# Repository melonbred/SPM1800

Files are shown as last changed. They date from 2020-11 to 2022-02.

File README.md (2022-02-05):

# SPM1800
This is a PCB for a southpaw mini 1800 layout keyboard with the following features:

- Big bar and split bar support
- MX or Alps style switches
- Two independent rotary encoders
- USB Type-C
- Breakout pins for RGB underglow
- Breakout pin for USB shield ground

## WARNING
This PCB has been tested for functionality. However, please review the project files prior to placing an order for manufacturing. Users should be warned that they are manufacturing this at their own risk. 

## Layout
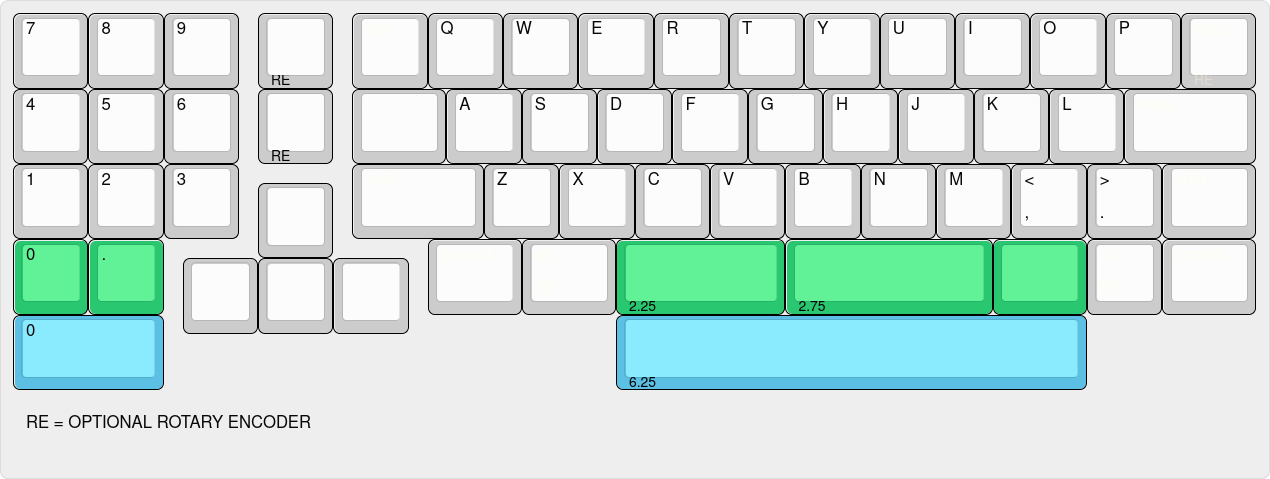
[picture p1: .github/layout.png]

[KLE](http://www.keyboard-layout-editor.com/#/gists/ef914cc294dadcf20cfa8c7b7239d802)

## PCB

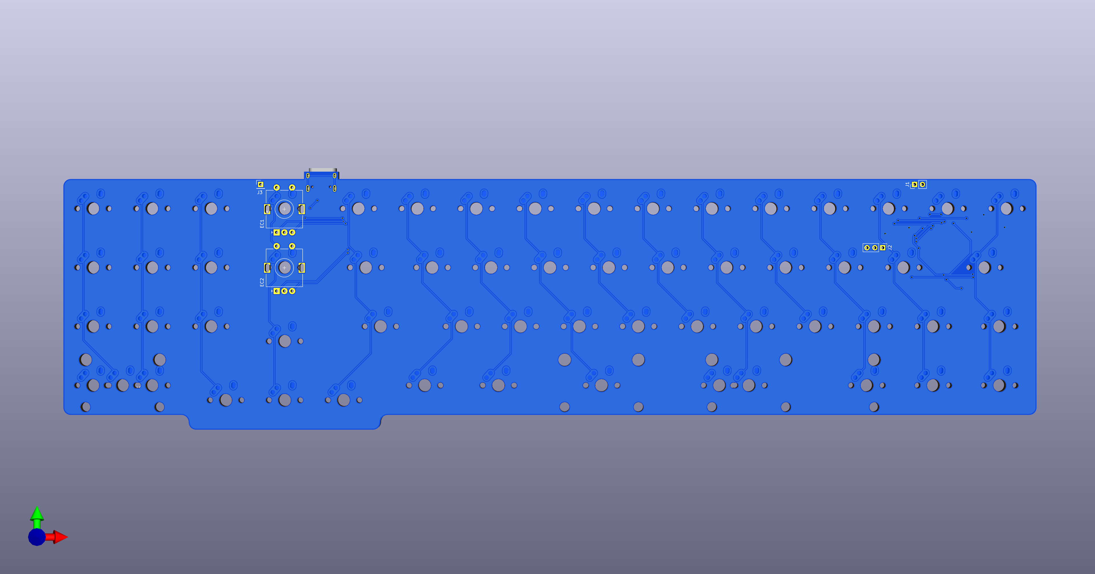
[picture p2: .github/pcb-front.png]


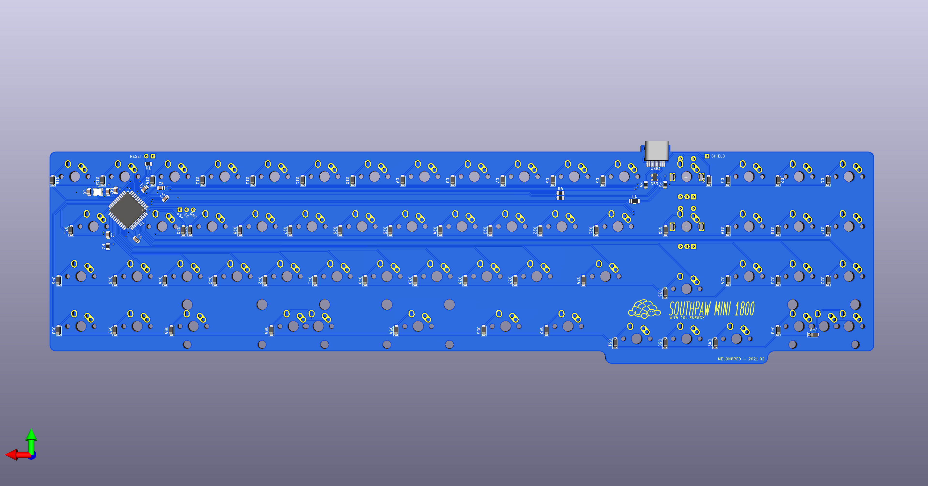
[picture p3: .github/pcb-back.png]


## BOM

| Designator | Description | Package | QTY | LCSC Part Number |
|---|---|---|-----|---|
|C1, C2, C3, C4|Capacitor - 0.1uF|0805|4|C28233|
|C5|Capacitor - 10uF|0805|1|C15850|
|C6, C7|Capacitor - 22pF|0805|2|C1804|
|C8|Capacitor - 1uF|0805|1|C28323|
|D1 - D58|Diode - 1N4148|SOD-123|58|C466653|
|D59|ESD Protection Diode - PRTR5V0U2X|SOD-143B|1|C12333|
|F1|Fuse 24V - 500mA|1206|1|C70076|
|R1, R2|Resistor - 10k|0805|2|C17414|
|R3, R4|Resistor - 5.1k|0805|2|C27834|
|R5, R6|Resistor - 22|0805|2|C17561|
|U1|Atmega32u4|QFP-44_10x10mm_P0.8mm|1|C44854|
|USB1|HRO-TYPE-C-31-M-12|HRO-TYPE-C-31-M-12|1|C165948|
|Y1|Crystal 16Mhz 3.2x2.5mm, 4 pad|3225|1|C156247|

## QMK Firmware
Firmware has been written but not tested at this time. QMK files can be found [here](https://github.com/melonbred/SPM1800/tree/master/QMK).

## Additional Notes
This project uses KiCAD libraries maintained by ai03:

- [MX_Alps_Hybrid](https://github.com/ai03-2725/MX_Alps_Hybrid)
- [random-keyboard-parts.pretty](https://github.com/ai03-2725/random-keyboard-parts.pretty)
- [Type-C.pretty](https://github.com/ai03-2725/Type-C.pretty)

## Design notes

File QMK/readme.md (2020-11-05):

# spm1800

spm1800

A short description of the keyboard/project

* Keyboard Maintainer: [melonbred](https://github.com/yourusername)
* Hardware Supported: The PCBs, controllers supported
* Hardware Availability: Links to where you can find this hardware

Make example for this keyboard (after setting up your build environment):

    make spm1800:default

See the [build environment setup](https://docs.qmk.fm/#/getting_started_build_tools) and the [make instructions](https://docs.qmk.fm/#/getting_started_make_guide) for more information. Brand new to QMK? Start with our [Complete Newbs Guide](https://docs.qmk.fm/#/newbs).

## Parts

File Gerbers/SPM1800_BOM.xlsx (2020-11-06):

Designator | Quantity | Value | Footprint | LCSC Part #
C2, C3, C4, C1 | 4 | 0.1uF | Capacitor_SMD:C_0805_2012Metric | C730459
C5 | 1 | 10uF | Capacitor_SMD:C_0805_2012Metric | C307520
C6, C7 | 2 | 22pF | Capacitor_SMD:C_0805_2012Metric | C1804
C8 | 1 | 1uF | Capacitor_SMD:C_0805_2012Metric | C116352
D1, D2, D3, D17, D18, D19, D32, D33, D34, D47, D48, D4, D20, D35, D49, D50, D5, D6, D7, D8, D9, D10, D11, D12, D13, D14, D15, D16, D21, D22, D23, D24, D25, D26, D27, D28, D29, D30, D31, D36, D37, D38, D39, D40, D41, D42, D43, D44, D45, D46, D51, D52, D53, D54, D55, D56, D57, D58 | 58 | 1N4148 | Diode_SMD:D_SOD-123 | C466653
D59 | 1 | PRTR5V0U2X | SOT143B | C78442
F1 | 1 | Polyfuse_Small | Fuse:Fuse_1206_3216Metric | C70076
R1 R2 | 2 | 10k | Resistor_SMD:R_0805_2012Metric | C365230
R3 R4 | 2 | 5.1k | Resistor_SMD:R_0805_2012Metric | C328405
R5 R6 | 2 | 22 | Resistor_SMD:R_0805_2012Metric | C178169
Y1 | 1 | Crystal_GND24_Small | Crystal:Crystal_SMD_3225-4Pin_3.2x2.5mm | C156247

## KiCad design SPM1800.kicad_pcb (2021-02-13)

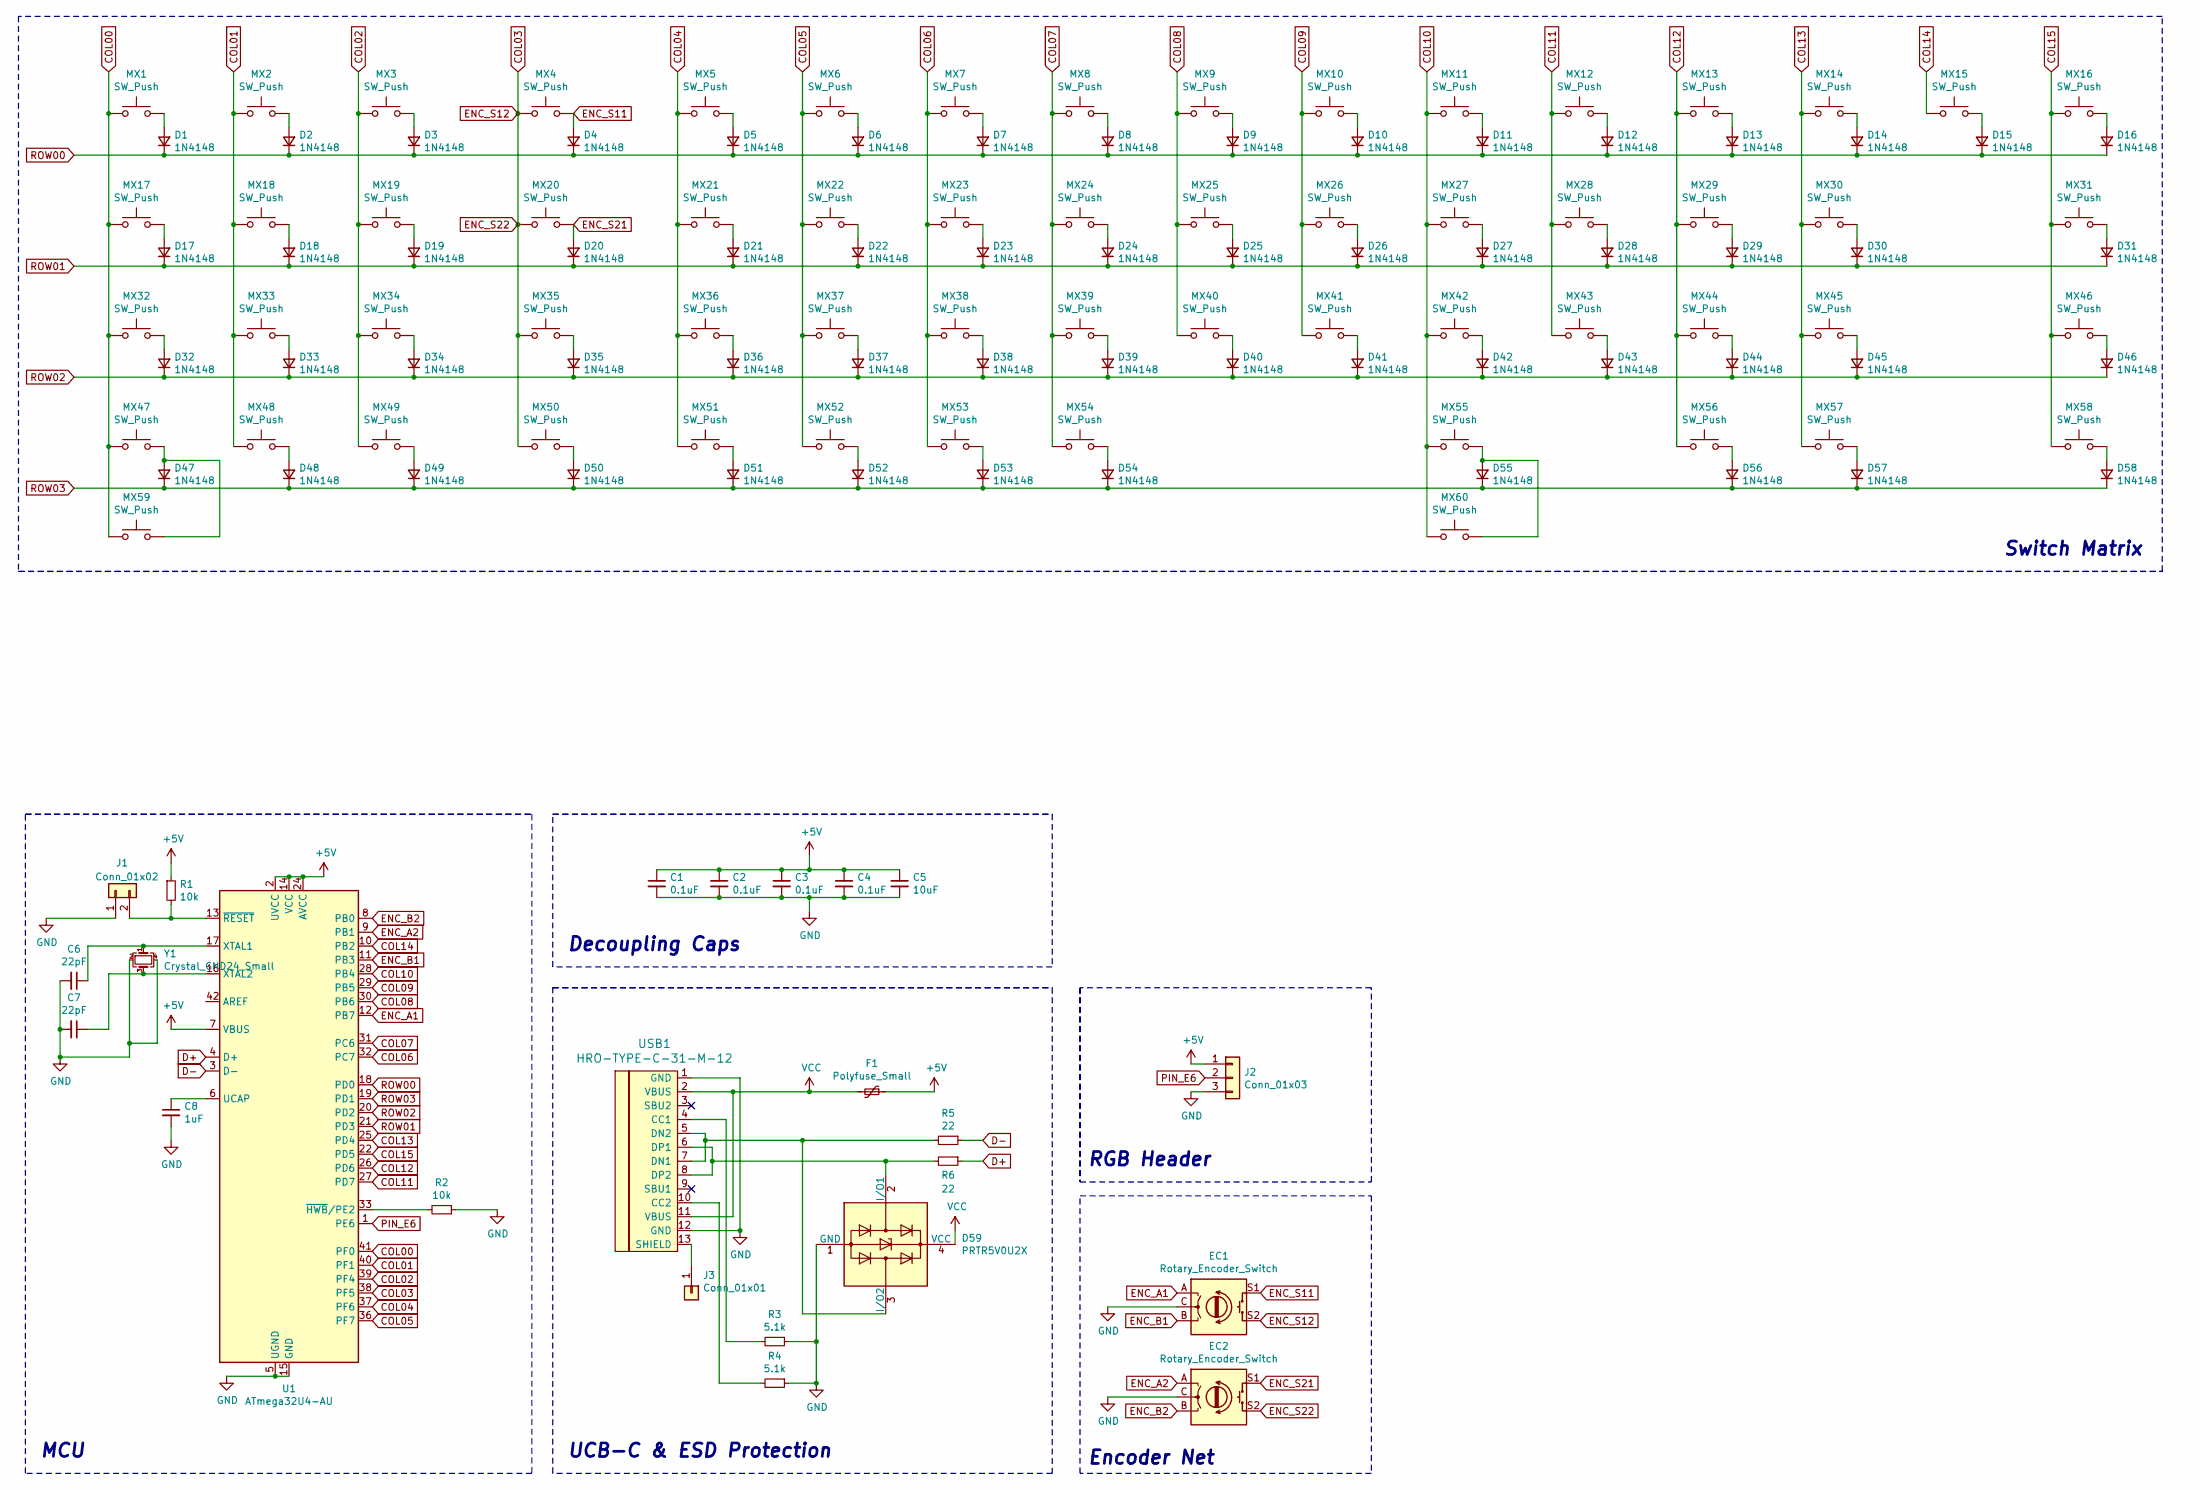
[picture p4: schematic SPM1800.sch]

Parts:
C1, C2, C3, C4: 0.1uF; C_0805_2012Metric
C5: 10uF; C_0805_2012Metric
C6, C7: 22pF; C_0805_2012Metric
C8: 1uF; C_0805_2012Metric
D1, D2, D3, D4, D5, D6, D7, D8, D9, D10, D11, D12, D13, D14, D15, D16, D17, D18, D19, D20, D21, D22, D23, D24, D25, D26, D27, D28, D29, D30, D31, D32, D33, D34, D35, D36, D37, D38, D39, D40, D41, D42, D43, D44, D45, D46, D47, D48, D49, D50, D51, D52, D53, D54, D55, D56, D57, D58: 1N4148; D_SOD-123
D59: PRTR5V0U2X; SOT143B
EC1, EC2: Rotary_Encoder_Switch; RotaryEncoder_Alps_EC11E-Switch_Vertical_H20mm
F1: Polyfuse_Small; Fuse_1206_3216Metric
J1: Conn_01x02; PinHeader_1x02_P2.54mm_Vertical
J2: Conn_01x03; PinHeader_1x03_P2.54mm_Vertical
J3: Conn_01x01; PinHeader_1x01_P2.54mm_Vertical
MX1, MX2, MX3, MX4, MX5, MX6, MX7, MX8, MX9, MX10, MX11, MX12, MX13, MX14, MX15, MX16, MX17, MX18, MX19, MX20, MX22, MX23, MX24, MX25, MX26, MX27, MX28, MX29, MX30, MX32, MX33, MX34, MX35, MX37, MX38, MX39, MX40, MX41, MX42, MX43, MX44, MX45, MX47, MX48, MX49, MX50, MX51, MX57: SW_Push; MX-1U-NoLED
MX21, MX46, MX52, MX53, MX56, MX58: SW_Push; MX-1.25U-NoLED
MX31, MX36: SW_Push; MX-1.75U-NoLED
MX54: SW_Push; MX-2.25U-ReversedStabilizers-NoLED
MX55: SW_Push; MX-2.75U-ReversedStabilizers-NoLED
MX59: SW_Push; MX-2U-ReversedStabilizers-NoLED
MX60: SW_Push; MX-6.25U-ReversedStabilizers-NoLED
R1, R2: 10k; R_0805_2012Metric
R3, R4: 5.1k; R_0805_2012Metric
R5, R6: 22; R_0805_2012Metric
U1: ATmega32U4-AU; TQFP-44_10x10mm_P0.8mm
USB1: HRO-TYPE-C-31-M-12; HRO-TYPE-C-31-M-12-HandSoldering
Y1: Crystal_GND24_Small; Crystal_SMD_3225-4Pin_3.2x2.5mm

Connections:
+5V: C1.1, C2.1, C3.1, C4.1, C5.1, F1.1, J2.1, R1.1, U1.2 (UVCC), U1.7 (VBUS), U1.14 (VCC), U1.24 (AVCC), U1.34 (VCC), U1.44 (AVCC)
COL00: MX1.1, MX17.1, MX32.1, MX47.1, MX59.1, U1.41 (PF0)
COL01: MX2.1, MX18.1, MX33.1, MX48.1, U1.40 (PF1)
COL02: MX3.1, MX19.1, MX34.1, MX49.1, U1.39 (PF4)
COL03: EC1.S2, EC2.S2, MX4.1, MX20.1, MX35.1, MX50.1, U1.38 (PF5)
COL04: MX5.1, MX21.1, MX36.1, MX51.1, U1.37 (PF6)
COL05: MX6.1, MX22.1, MX37.1, MX52.1, U1.36 (PF7)
COL06: MX7.1, MX23.1, MX38.1, MX53.1, U1.32 (PC7)
COL07: MX8.1, MX24.1, MX39.1, MX54.1, U1.31 (PC6)
COL08: MX9.1, MX25.1, MX40.1, U1.30 (PB6)
COL09: MX10.1, MX26.1, MX41.1, U1.29 (PB5)
COL10: MX11.1, MX27.1, MX42.1, MX55.1, MX60.1, U1.28 (PB4)
COL11: MX12.1, MX28.1, MX43.1, U1.27 (PD7)
COL12: MX13.1, MX29.1, MX44.1, MX56.1, U1.26 (PD6)
COL13: MX14.1, MX30.1, MX45.1, MX57.1, U1.25 (PD4)
COL14: MX15.1, U1.10 (PB2)
COL15: MX16.1, MX31.1, MX46.1, MX58.1, U1.22 (PD5)
D+: R6.1, U1.4 (D+)
D-: R5.1, U1.3 (D-)
ENC_A1: EC1.A, U1.12 (PB7)
ENC_A2: EC2.A, U1.9 (PB1)
ENC_B1: EC1.B, U1.11 (PB3)
ENC_B2: EC2.B, U1.8 (PB0)
ENC_S11: D4.2 (A), EC1.S1, MX4.2
ENC_S21: D20.2 (A), EC2.S1, MX20.2
GND: C1.2, C2.2, C3.2, C4.2, C5.2, C6.2, C7.2, C8.2, D59.1 (GND), EC1.C, EC2.C, J1.1, J2.3, R2.1, R3.1, R4.1, U1.5 (UGND), U1.15 (GND), U1.23 (GND), U1.35 (GND), U1.43 (GND), USB1.1 (GND), USB1.12 (GND), Y1.2, Y1.4
unnamed: C6.1, U1.17 (XTAL1), Y1.1
unnamed: C7.1, U1.16 (XTAL2), Y1.3
unnamed: C8.1, U1.6 (UCAP)
unnamed: D1.2 (A), MX1.2
unnamed: D2.2 (A), MX2.2
unnamed: D3.2 (A), MX3.2
unnamed: D5.2 (A), MX5.2
unnamed: D6.2 (A), MX6.2
unnamed: D7.2 (A), MX7.2
unnamed: D8.2 (A), MX8.2
unnamed: D9.2 (A), MX9.2
unnamed: D10.2 (A), MX10.2
unnamed: D11.2 (A), MX11.2
unnamed: D12.2 (A), MX12.2
unnamed: D13.2 (A), MX13.2
unnamed: D14.2 (A), MX14.2
unnamed: D15.2 (A), MX15.2
unnamed: D16.2 (A), MX16.2
unnamed: D17.2 (A), MX17.2
unnamed: D18.2 (A), MX18.2
unnamed: D19.2 (A), MX19.2
unnamed: D21.2 (A), MX21.2
unnamed: D22.2 (A), MX22.2
unnamed: D23.2 (A), MX23.2
unnamed: D24.2 (A), MX24.2
unnamed: D25.2 (A), MX25.2
unnamed: D26.2 (A), MX26.2
unnamed: D27.2 (A), MX27.2
unnamed: D28.2 (A), MX28.2
unnamed: D29.2 (A), MX29.2
unnamed: D30.2 (A), MX30.2
unnamed: D31.2 (A), MX31.2
unnamed: D32.2 (A), MX32.2
unnamed: D33.2 (A), MX33.2
unnamed: D34.2 (A), MX34.2
unnamed: D35.2 (A), MX35.2
unnamed: D36.2 (A), MX36.2
unnamed: D37.2 (A), MX37.2
unnamed: D38.2 (A), MX38.2
unnamed: D39.2 (A), MX39.2
unnamed: D40.2 (A), MX40.2
unnamed: D41.2 (A), MX41.2
unnamed: D42.2 (A), MX42.2
unnamed: D43.2 (A), MX43.2
unnamed: D44.2 (A), MX44.2
unnamed: D45.2 (A), MX45.2
unnamed: D46.2 (A), MX46.2
unnamed: D47.2 (A), MX47.2, MX59.2
unnamed: D48.2 (A), MX48.2
unnamed: D49.2 (A), MX49.2
unnamed: D50.2 (A), MX50.2
unnamed: D51.2 (A), MX51.2
unnamed: D52.2 (A), MX52.2
unnamed: D53.2 (A), MX53.2
unnamed: D54.2 (A), MX54.2
unnamed: D55.2 (A), MX55.2, MX60.2
unnamed: D56.2 (A), MX56.2
unnamed: D57.2 (A), MX57.2
unnamed: D58.2 (A), MX58.2
unnamed: D59.2 (I/O1), R6.2, USB1.6 (DP1), USB1.8 (DP2)
unnamed: D59.3 (I/O2), R5.2, USB1.5 (DN2), USB1.7 (DN1)
unnamed: J1.2, R1.2, U1.13 (~RESET)
unnamed: J3.1, USB1.13 (SHIELD)
unnamed: R2.2, U1.33 (~HWB~/PE2)
unnamed: R3.2, USB1.4 (CC1)
unnamed: R4.2, USB1.10 (CC2)
PIN_E6: J2.2, U1.1 (PE6)
ROW00: D1.1 (K), D2.1 (K), D3.1 (K), D4.1 (K), D5.1 (K), D6.1 (K), D7.1 (K), D8.1 (K), D9.1 (K), D10.1 (K), D11.1 (K), D12.1 (K), D13.1 (K), D14.1 (K), D15.1 (K), D16.1 (K), U1.18 (PD0)
ROW01: D17.1 (K), D18.1 (K), D19.1 (K), D20.1 (K), D21.1 (K), D22.1 (K), D23.1 (K), D24.1 (K), D25.1 (K), D26.1 (K), D27.1 (K), D28.1 (K), D29.1 (K), D30.1 (K), D31.1 (K), U1.21 (PD3)
ROW02: D32.1 (K), D33.1 (K), D34.1 (K), D35.1 (K), D36.1 (K), D37.1 (K), D38.1 (K), D39.1 (K), D40.1 (K), D41.1 (K), D42.1 (K), D43.1 (K), D44.1 (K), D45.1 (K), D46.1 (K), U1.20 (PD2)
ROW03: D47.1 (K), D48.1 (K), D49.1 (K), D50.1 (K), D51.1 (K), D52.1 (K), D53.1 (K), D54.1 (K), D55.1 (K), D56.1 (K), D57.1 (K), D58.1 (K), U1.19 (PD1)
VCC: D59.4 (VCC), F1.2, USB1.2 (VBUS), USB1.11 (VBUS)

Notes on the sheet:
MCU
UCB-C & ESD Protection
Decoupling Caps
Switch Matrix
Encoder Net
RGB Header

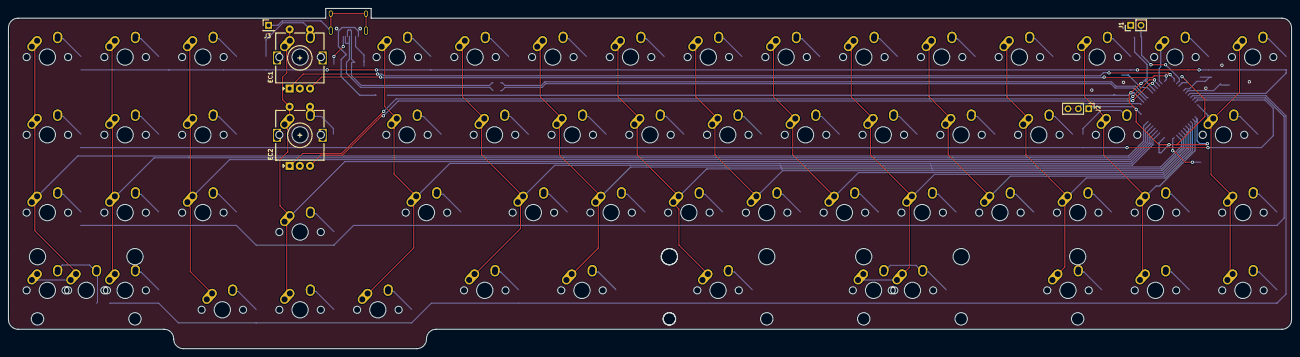
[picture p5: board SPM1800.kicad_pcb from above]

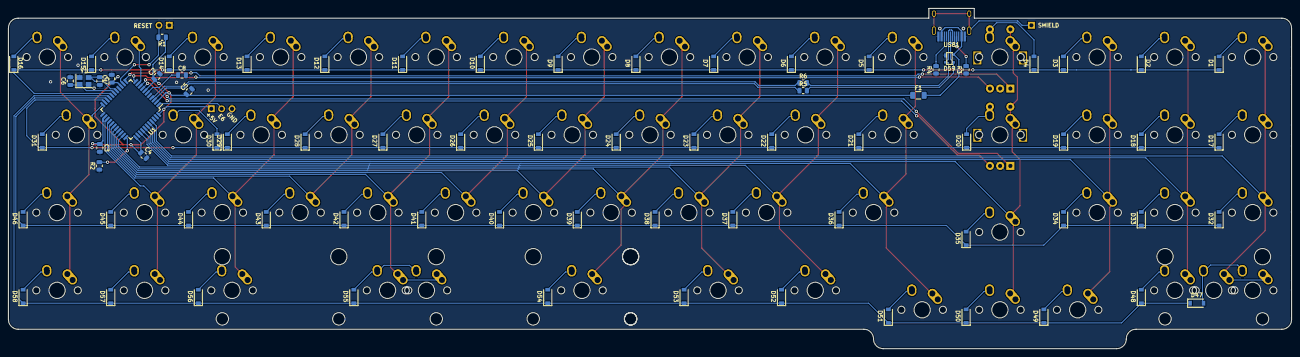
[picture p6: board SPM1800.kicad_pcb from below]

Board: 2 copper layers, 314.3 x 83.3 mm, 142 parts (77 on the bottom side), 98 nets.

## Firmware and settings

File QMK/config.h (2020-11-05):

/*
Copyright 2020 melonbred

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
You should have received a copy of the GNU General Public License
along with this program.  If not, see <http://www.gnu.org/licenses/>.
*/

#pragma once

#include "config_common.h"

/* USB Device descriptor parameter */
#define VENDOR_ID 0xFEED
#define PRODUCT_ID 0x0000
#define DEVICE_VER 0x0001
#define MANUFACTURER melonbred
#define PRODUCT spm1800
#define DESCRIPTION southpaw mini 1800-layout

/* key matrix size */
#define MATRIX_ROWS 4
#define MATRIX_COLS 16

/*
 * Keyboard Matrix Assignments
 *
 * Change this to how you wired your keyboard
 * COLS: AVR pins used for columns, left to right
 * ROWS: AVR pins used for rows, top to bottom
 * DIODE_DIRECTION: COL2ROW = COL = Anode (+), ROW = Cathode (-, marked on diode)
 *                  ROW2COL = ROW = Anode (+), COL = Cathode (-, marked on diode)
 *
 */
#define MATRIX_ROW_PINS { D0, D3, D2, D1 }
#define MATRIX_COL_PINS { F0, F1, F4, F5, F6, F7, C7, C6, B6, B5, B4, D7, D6, D4, B2, D5 }
#define UNUSED_PINS 

/* COL2ROW, ROW2COL*/
#define DIODE_DIRECTION COL2ROW

/*Encoder Definitions*/
#define ENCODERS_PAD_A { B7, B1 }
#define ENCODERS_PAD_B { B3, B0 }


// #define RGB_DI_PIN E6
// #ifdef RGB_DI_PIN
//   #define RGBLED_NUM 16
//   #define RGBLIGHT_HUE_STEP 8
//   #define RGBLIGHT_SAT_STEP 8
//   #define RGBLIGHT_VAL_STEP 8
//   #define RGBLIGHT_LIMIT_VAL 255 /* The maximum brightness level */
//   #define RGBLIGHT_SLEEP  /* If defined, the RGB lighting will be switched off when the host goes to sleep */
// /*== all animations enable ==*/
//   #define RGBLIGHT_ANIMATIONS
// /*== or choose animations ==*/
//   #define RGBLIGHT_EFFECT_BREATHING
//   #define RGBLIGHT_EFFECT_RAINBOW_MOOD
//   #define RGBLIGHT_EFFECT_RAINBOW_SWIRL
//   #define RGBLIGHT_EFFECT_SNAKE
//   #define RGBLIGHT_EFFECT_KNIGHT
//   #define RGBLIGHT_EFFECT_CHRISTMAS
//   #define RGBLIGHT_EFFECT_STATIC_GRADIENT
//   #define RGBLIGHT_EFFECT_RGB_TEST
//   #define RGBLIGHT_EFFECT_ALTERNATING
// /*== customize breathing effect ==*/
//   /*==== (DEFAULT) use fixed table instead of exp() and sin() ====*/
//   #define RGBLIGHT_BREATHE_TABLE_SIZE 256      // 256(default) or 128 or 64
//   /*==== use exp() and sin() ====*/
//   #define RGBLIGHT_EFFECT_BREATHE_CENTER 1.85  // 1 to 2.7
//   #define RGBLIGHT_EFFECT_BREATHE_MAX    255   // 0 to 255
// #endif

/* Debounce reduces chatter (unintended double-presses) - set 0 if debouncing is not needed */
#define DEBOUNCE 5

/* define if matrix has ghost (lacks anti-ghosting diodes) */
//#define MATRIX_HAS_GHOST

/* Mechanical locking support. Use KC_LCAP, KC_LNUM or KC_LSCR instead in keymap */
#define LOCKING_SUPPORT_ENABLE
/* Locking resynchronize hack */
#define LOCKING_RESYNC_ENABLE

/* If defined, GRAVE_ESC will always act as ESC when CTRL is held.
 * This is userful for the Windows task manager shortcut (ctrl+shift+esc).
 */
// #define GRAVE_ESC_CTRL_OVERRIDE

/*
 * Force NKRO
 *
 * Force NKRO (nKey Rollover) to be enabled by default, regardless of the saved
 * state in the bootmagic EEPROM settings. (Note that NKRO must be enabled in the
 * makefile for this to work.)
 *
 * If forced on, NKRO can be disabled via magic key (default = LShift+RShift+N)
 * until the next keyboard reset.
 *
 * NKRO may prevent your keystrokes from being detected in the BIOS, but it is
 * fully operational during normal computer usage.
 *
 * For a less heavy-handed approach, enable NKRO via magic key (LShift+RShift+N)
 * or via bootmagic (hold SPACE+N while plugging in the keyboard). Once set by
 * bootmagic, NKRO mode will always be enabled until it is toggled again during a
 * power-up.
 *
 */
//#define FORCE_NKRO

/*
 * Magic Key Options
 *
 * Magic keys are hotkey commands that allow control over firmware functions of
 * the keyboard. They are best used in combination with the HID Listen program,
 * found here: https://www.pjrc.com/teensy/hid_listen.html
 *
 * The options below allow the magic key functionality to be changed. This is
 * useful if your keyboard/keypad is missing keys and you want magic key support.
 *
 */

/* key combination for magic key command */
/* defined by default; to change, uncomment and set to the combination you want */
// #define IS_COMMAND() (get_mods() == MOD_MASK_SHIFT)

/* control how magic key switches layers */
//#define MAGIC_KEY_SWITCH_LAYER_WITH_FKEYS  true
//#define MAGIC_KEY_SWITCH_LAYER_WITH_NKEYS  true
//#define MAGIC_KEY_SWITCH_LAYER_WITH_CUSTOM false
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

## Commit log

2020-11-01 Added gerbers
    [SPM1800-B_Cu.gbr, SPM1800-B_Mask.gbr, SPM1800-B_Paste.gbr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]
2020-11-01 Updated BOM
    [SPM1800.kicad_pcb]
2020-11-04 Updated PCB
    Added series resistors to data lines.
    [SPM1800-B_Cu.gbr, SPM1800-B_Mask.gbr, SPM1800-B_Paste.gbr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]
2020-11-04 Msc. Update
    PCB images updated.
    Fixed formatting
2020-11-04 Msc. Updated
    PCB images.
    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
2020-11-05 Updated PCB
    COL13 to D4
    COL15 to D5
    [SPM1800.kicad_pcb, SPM1800.sch]
2020-11-06 Updated Gerbers
    [SPM1800-B_Cu.gbr, SPM1800-B_Mask.gbr, SPM1800-B_Paste.gbr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]
2020-11-07 Prepared production files
    For prototyping
    [SPM1800-B_Cu.gbr, SPM1800-B_Mask.gbr, SPM1800-B_SilkS.gbr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]
2021-02-13 Quick Fix
    [SPM1800-B_Cu.gbr, SPM1800-B_Mask.gbr, SPM1800-B_SilkS.gbr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]
2021-02-13 Added kamelon pan
    [SPM1800-B_Cu.gbr, SPM1800-B_Mask.gbr, SPM1800-B_SilkS.gbr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]
2021-02-27 Update BOM

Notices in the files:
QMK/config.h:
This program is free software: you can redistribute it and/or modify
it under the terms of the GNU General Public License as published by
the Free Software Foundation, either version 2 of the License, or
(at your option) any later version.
